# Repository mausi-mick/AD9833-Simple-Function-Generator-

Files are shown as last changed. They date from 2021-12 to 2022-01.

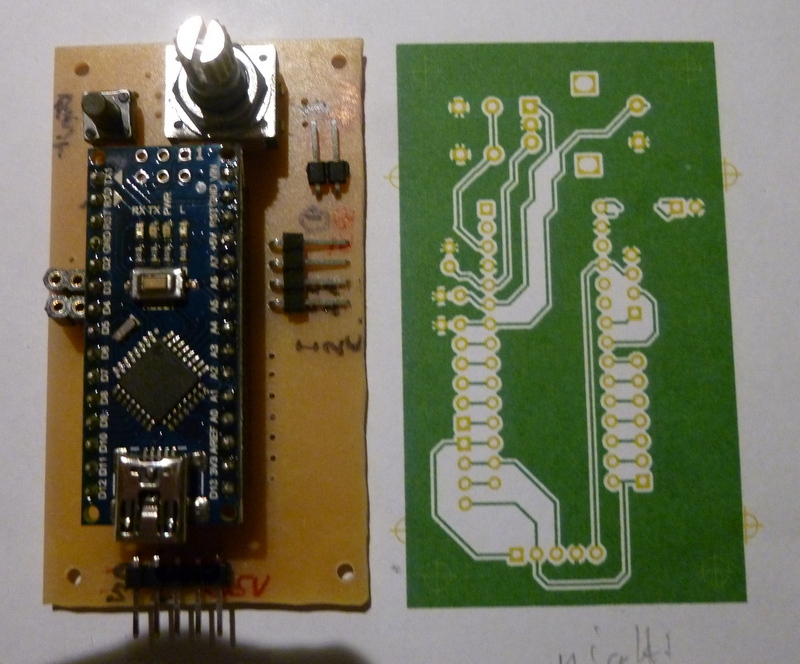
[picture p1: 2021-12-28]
P1000197.JPG

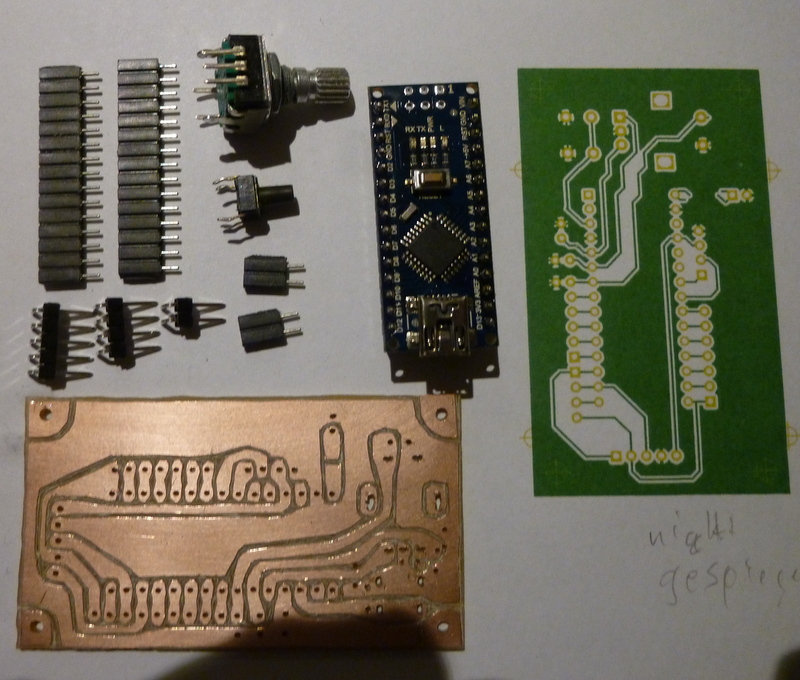
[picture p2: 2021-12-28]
P1000195.JPG

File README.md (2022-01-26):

AD9833-Simple-Function-Generator

The project based on the project "Signal Generator AD9833" from Peter Balch :
    •  https://www.instructables.com/Signal-Generator-AD9833/
    • where the input commands like Curve-Type (Sine, Triangle, Square) , Sweep or Frequency are send from a PC via USB to Arduino-Nano and from there to the AD9833 Signalgenerator-Modul.
    • I changed the program  so that it works standalone without connection to the PC.
    • For input the commands, I use only a rotary encoder with integrated push-button-switch.
    • A HD44780 display (LCD1602) shows all information (Curve-Type, Frequency, sweep ...)
    • On the encoder I use external interrupts (Pin2 / Pin3 Arduino NANO) , on push-button-switch I use Pin-Change-Interrupt (PCI) for a direct/quick response.
    • A small Video is here:   https://www.youtube.com/watch?v=DLXJh2jmxDk
    • or here: video  („TRIANGLE“) :   https://www.youtube.com/watch?v=seZB-FUj7es
    • In the new version I have expand the program with new functions inside the AD9833-Signal-Generator and outside this function with a digital ConstantCurrentSource (CCS) working from about 1µA ( starts at 10 µA ) to 4095 µA (step 1 µA) or from 10 µA to 40.95 mA (step 10 µA) .
    • I have expand now the device (and program) with a second sine-generator (AD9850) module,
    • so you have two independent siganl-sources.

So the device  includes now this functions:

    • AD9833 Signalgenerator for Sine, Triangle and Squarewave up to 12.5 Mhz in 1 Hz-Steps 
      
    • digital ConstantCurrentSource/Sink from 10 µA to 4.095 mA (Stepwidth : 1 µA) or (10 µA to 40.95 mA with stepwidth 10 µA) 
    • Low-Frequency Function-Generator for Sinus, Triangle StepUp , StepDown and Squarewave for low frequencies (mHz to some kHz) 
    • optionally : AD9850  Sine-genarator  (second siganl-source)
    • 
For small budget I use only a few parts with price over 1 $/€:

    • AD9833 board
    • AD9850 board (optional)
    • HD44780 with I2C 
    • Arduino NANO (clone?) 
    • DAC MCP4822 
    • OPV MCP6002 
    • n-Mosfet BSP89  (high Voltage, low Idss)
    • Rotary Encoder with push-button 
    • n-Mosfet for switching Rp ( from 1025 Ohm to 10.25 Ohm) with Low R-on (< 100 mOhm) 
    • 5V Zener/Ref-Diode  (or other stabilization for MCP4822/MCP6002) 
    • 2x MT3608 Step up (5V/ for NANO/LCD..., 28V for CurrentSource) 
    • Battery-holder for 18650 Battery 
    • USB  Lion-loader board 
    • 18650 Lion-Battery (one piece) 
    • 
More information in the next days.

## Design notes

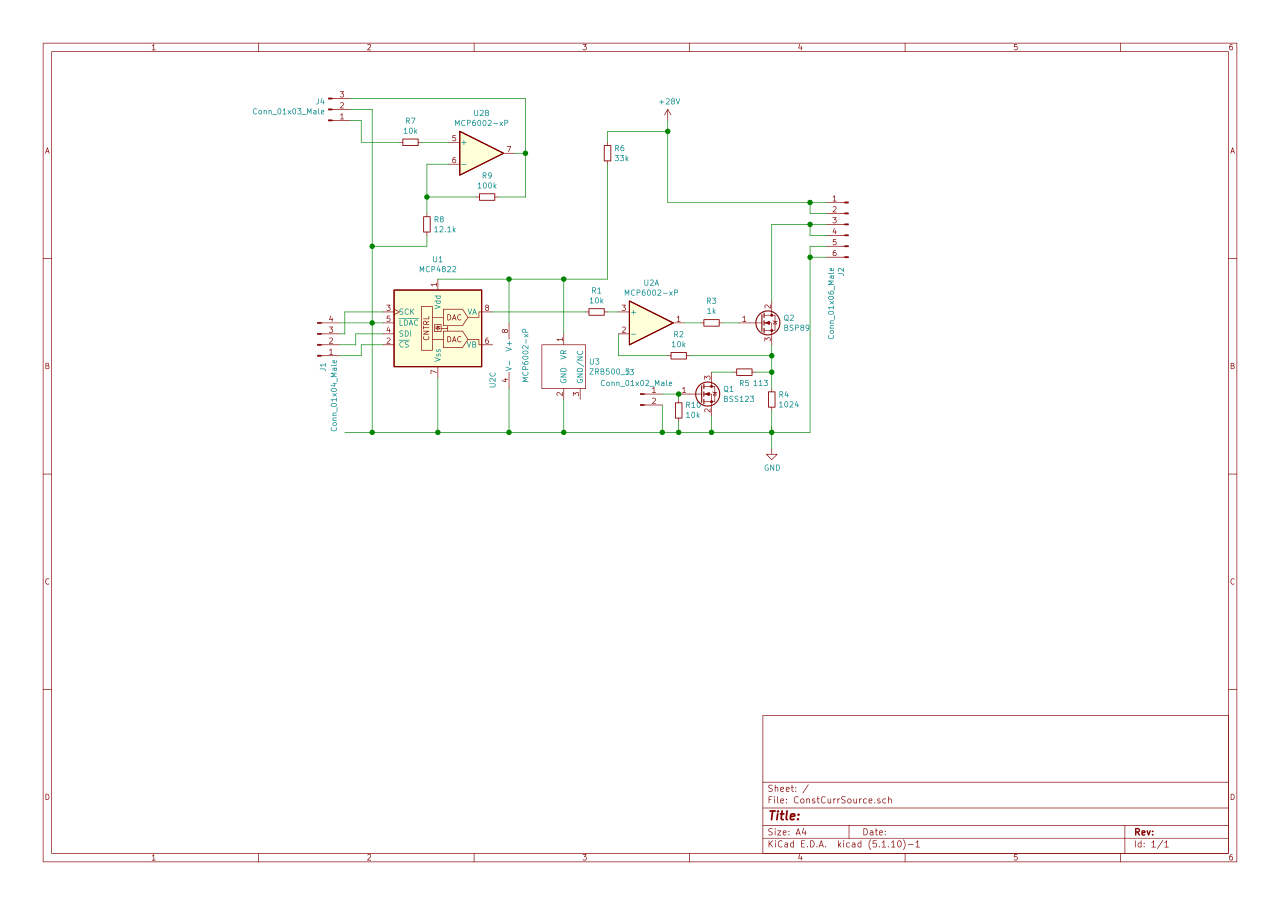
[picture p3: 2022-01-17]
ConstCurrSource(1).png

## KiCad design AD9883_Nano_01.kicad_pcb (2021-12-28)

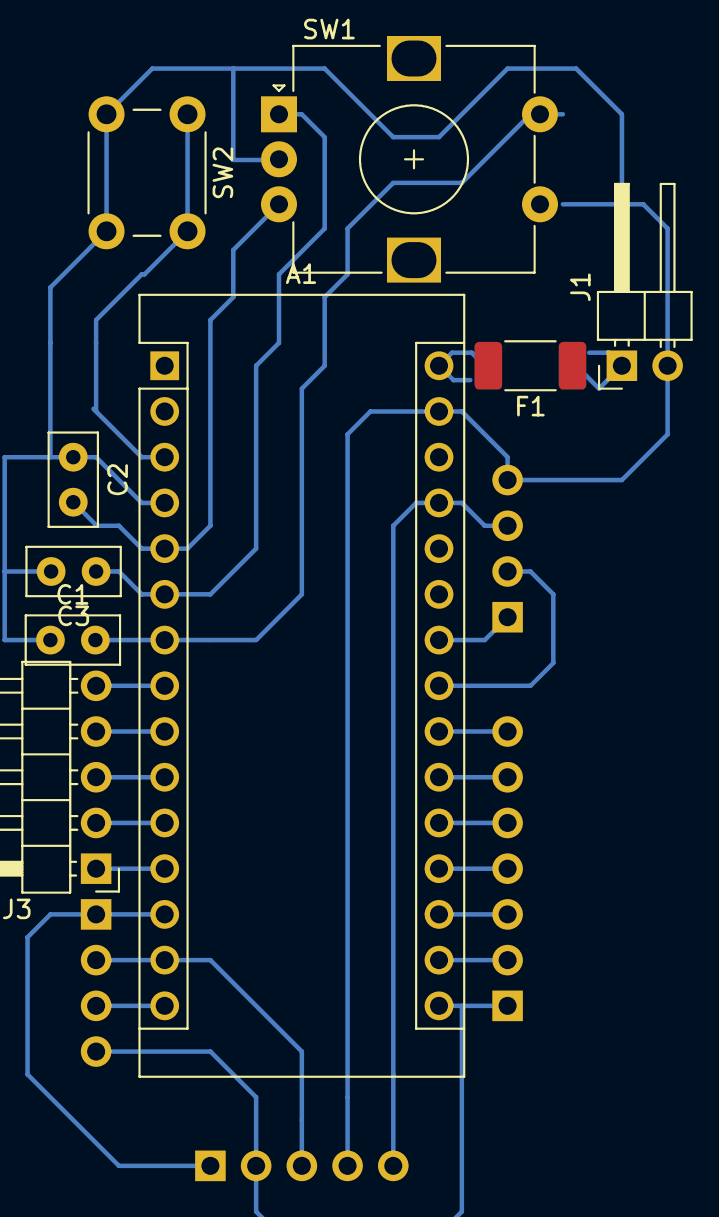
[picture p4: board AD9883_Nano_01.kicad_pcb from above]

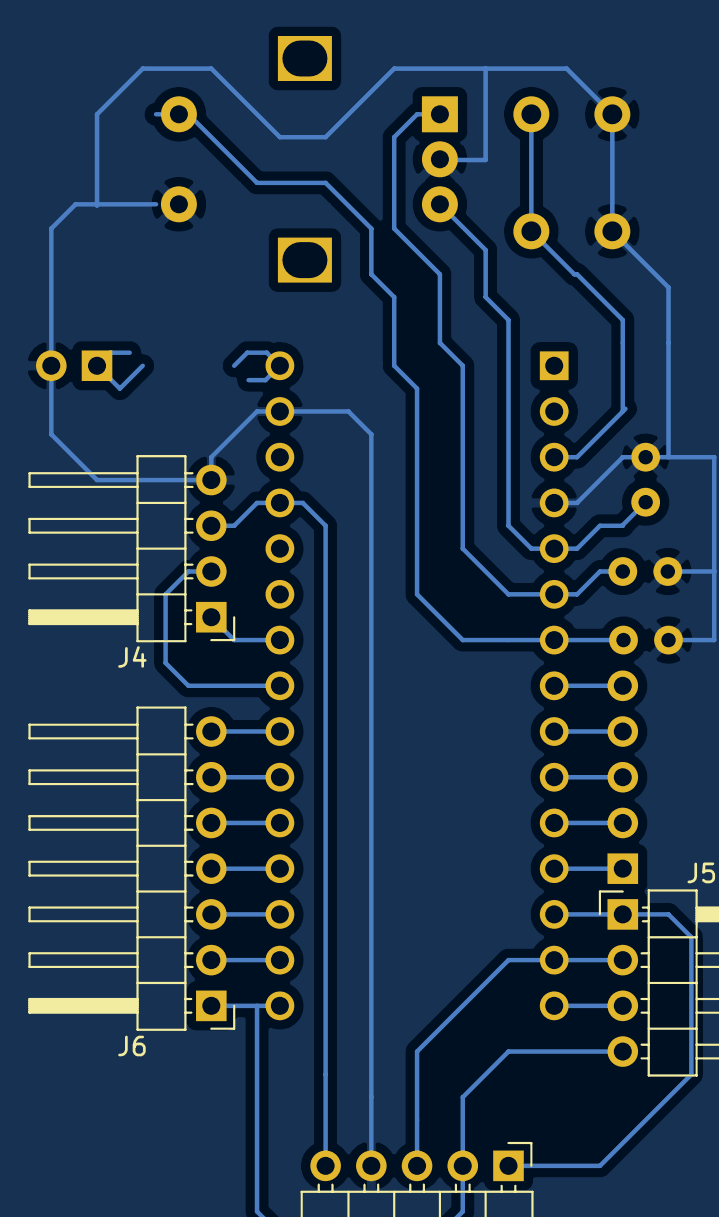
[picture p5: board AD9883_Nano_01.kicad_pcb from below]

Board: 2 copper layers, 13 parts (4 on the bottom side), 25 nets.

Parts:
A1: Arduino_Nano_v3.x; Arduino_Nano
C1, C2, C3: 10nF; C_Disc_D5.0mm_W2.5mm_P2.50mm
F1: Fuse_Small 500mA; Fuse_2010_5025Metric_Pad1.52x2.65mm_HandSolder
J1: Conn_Power_7_12V; PinHeader_1x02_P2.54mm_Horizontal
J2: Conn_to_AD9833; PinHeader_1x05_P2.54mm_Horizontal
J3: Conn_open; PinHeader_1x05_P2.54mm_Horizontal
J4: Conn_to_I2C_LCD; PinHeader_1x04_P2.54mm_Horizontal
J5: Conn_SPI; PinHeader_1x04_P2.54mm_Horizontal
J6: Conn_ADC; PinHeader_1x07_P2.54mm_Horizontal
SW1: Rotary_Encoder_Switch; RotaryEncoder_Alps_EC12E-Switch_Vertical_H20mm
SW2: SW_DIP_x01; SW_PUSH_6mm_H7.3mm

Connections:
+5V: A1.27, J2.5, J4.3
+9V: F1.1, J1.1
GND: A1.4, A1.29, C1.1, C2.1, C3.2, J1.2, J2.4, J4.4, SW1.C, SW1.S2, SW2.2
unnamed: A1.3, SW2.1
unnamed: A1.5, C2.2, SW1.B
unnamed: A1.6, C3.1, SW1.A
unnamed: A1.7, C1.2, SW1.S1
unnamed: A1.8, J3.5
unnamed: A1.9, J3.4
unnamed: A1.10, J3.3
unnamed: A1.11, J3.2
unnamed: A1.12, J3.1
unnamed: A1.13, J2.1, J5.1
unnamed: A1.14, J2.3, J5.2
unnamed: A1.15, J5.3
unnamed: A1.16, J2.2, J5.4, J6.1
unnamed: A1.17, J6.2
unnamed: A1.18, J6.3
unnamed: A1.19, J6.4
unnamed: A1.20, J6.5
unnamed: A1.21, J6.6
unnamed: A1.22, J6.7
unnamed: A1.23, J4.2
unnamed: A1.24, J4.1
unnamed: A1.30, F1.2

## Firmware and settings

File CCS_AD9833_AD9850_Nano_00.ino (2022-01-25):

//
//--------------------------------------------------------------------------------------- 
//  Thanks:
//
// Peter Balch  :  https://www.instructables.com/Signal-Generator-AD9833/               : AD9833 Source, flow-control, sweep, ...
// fhdm-devels  :  https://www.instructables.com/Simple-AD9833-Based-Signal-Generator/  : PinChangeInterrupt
// GreatScottLab:  https://www.instructables.com/DIY-FunctionWaveform-Generator/        : HD44780 display
//                 https://omerk.github.io/lcdchargen/                                  : Pixel-Generator HD44780 LCD Modules
//                 Interrupt-based (switches (PCI) by Simon Merrett, based on insight from Oleg Mazurov, Nick Gammon, rt, Steve Spence
//---------------------------------------------------------------------------------------
// subject to the GNU General Public License
//---------------------------------------------------------------------------------------
// Developped with Arduino IDE 1.8.4 / 1.8.13
//---------------------------------------------------------------------------------------
//
// CCS_AD9833_Nano_00: 2022_01_05: copy from  CCS_NanO_08 and AD9833_PCI_Nano_HD44780_02
// CCS_AD9833_Nano_01: 2022_01_08: copy from  00. Test freq-Lo with Steps like current-steps
// CCS_AD9833_Nano_02: 2022_01_22: copy from  01. Test current-source
// CCS_AD9833_Nano_03: 2022_01_25: copy from  02 and AD9850_Nano_PCI_01: Integration Sine-Gen. AD9850
// CCS_AD9833_AD9850_Nano_00: 2022_01_25: copy from CCS_AD9833_Nano_03: 
//
#include <SPI.h>                     // for DAC and AD9833
#include <AD9833.h>                  // test
#include <MCP4822.h>                 // DAC 12 bit
#include <Encoder.h>
#include <Wire.h>                    // Wire for I2C
#include <LiquidCrystal_I2C.h>       // HD55780 LCD1602

//------------------------  Encoder with ext. Interrupt: 
const int ENC_CW   =  2; // ext.Int. Pin D2 <<-- change with D3 wrong direction ???
const int ENC_CCW  =  3; // ext.int. Pin D3 <<-- change with D2 wrong direction ???
//------------------------  switches with Pin-Change-Interrupt (PCI): 

const int RESET    =  4; // AD9850 Modul
const int DATA     =  5; // AD9850 Modul
const int FQ_UD    =  6; // AD9850 Modul
const int W_CLK    =  7; // AD9850 Modul   

const int SWITCH_R =  8; // switch a resistor parallel to Rm for increasing current ##################
const int DAC_CS   =  9; // MCP4822 12-bit Dac

//------------------------  AD9833 SPI-Pins
const int SG_FSYNC = 10; // AD9833 SPI-CS
const int SG_DATA  = 11; // AD9833 SPI-MOSI
const int SG_CLK   = 13; // AD9833 SPI-SCLK

const int ENC_A0   = A0; // PCINT8  : Pin A0    // rotary encoder steps
const int ENC_A1   = A1; // PCINT9  : Pin A1    // rotary encoder steps

const int ENC_BUT  = A2; // PCINT10 : Pin A2

#define AD9850_CLOCK 125000000      // Module AD9850 crystal frequency. 


AD9833 ad9(SG_FSYNC);               // SCK and MOSI must CLK and DAT pins on the AD9833 for SPI   

LiquidCrystal_I2C lcd(0x27, 16, 2); // HEX-Address 0x27 (or 0x3F), 16 rows , 2 lines_I2C lcd(0x27, 20, 4)" 


MCP4822 dac= MCP4822(DAC_CS);       // CS-Pin 9, AD9833 on Pin 10  

Encoder myEnc(ENC_CW,ENC_CCW);

volatile int EncPos    = 0; //this variable stores our current value of encoder position. Change to int or uin16_t instead of byte if you want to record a larger range than 0-255
volatile int oldEncPos = 0; //stores the last encoder position value so we can compare to the current reading and see if it has changed (so we know when to print to the serial monitor)
volatile byte enc_dir  = 'r';
volatile uint8_t but_p = 0,but_c=0;
volatile unsigned long  incr = 0;
volatile long unsigned int freq_s = 1000,freq=1000;         // Set initial frequency.
volatile long unsigned int freqOld = freq;
volatile uint8_t s_Hz=0,s_step=0,s_upd = 1;
volatile int stepPointer = 0; 

//-----------------------------------------------------------------------------
// Global Constants
//-----------------------------------------------------------------------------
const byte numberOfDigits = 8;  // number of digits in the frequency

const uint16_t wft_s = 0x2000; // sine
const uint16_t wft_t = 0x2002; // triangle
const uint16_t wft_q = 0x2028; // square
const uint16_t wft_h = 0x2020; // halfsquare

//const int wSine     = 0b0000000000000000;
//const int wTriangle = 0b0000000000000010;
//const int wSquare   = 0b0000000000101000;
const int step_t[]    = {1,2,3,5,6,9,10,15,30};                           // step-sine  0...8          
const uint16_t sweep_t[] = {1000,2000,5000,10000,20000,50000};            // sweep-pos 
const uint16_t delay_t[] = {100,200,500,1,2,5,10,20,50,100,200,500,1000}; // delay
const long f_st[] = { 0,10,100,1000,10000,100000,1000000};                // strt frequency
const char* stepText[] = {"   1 Hz", "   2 Hz", "   5 Hz", "  10 Hz", "  20 Hz", "  50 Hz", " 100 Hz", " 200 Hz", " 500 Hz",
                            "  1 kHz", "  2 kHz", "  5 kHz", " 10 kHz", " 20 kHz", " 50 kHz", "100 kHz", "200 kHz", "500 kHz"};
String units = stepText[stepPointer];
//                     0   1   2   3   4   5   6   7   8   9  10  11  12
const char com_t[] = {'S','T','Q','L','C','H','M','P','D','G','R','X',' '};   // Menu-Commands:
// 0  'S': start Sine 
// 1  'T': start Triangle 
// 2  'Q': start Square
// 3  'L': set Freq.-Low 
// 4  'C': set Freq.-Low scroll contin. or steps 
// 5  'H': set Freq.-High
// 6  'M': swap Freq. Low  <--> High
// 7  'P': set sweep param. up/down,  step-nr
// 8  'D': set / change Delay sweep
// 9  'G': sweep 
//10  'R': Reset AD9833
//11  'X': return 

const char *str_com[]= {"Sine            ","Triangle        ","Square          ",
                        "set Low freq.   ","scroll Stepw >=1","set High freq.  ",
                        "swap Lo/Hi freq.","set sweep param.","set delay sweep ",
                        "sweep           ","Reset AD9833    ","return          "}; 

// HD44780 special-signs

const byte C_C_1_Arrow_D[8] = {  // from: https://omerk.github.io/lcdchargen/
  0b01110, 0b01010, 0b01010, 0b01010, 0b01010, 0b11011, 0b01110, 0b00100};

const byte C_C_2_Arrow_U[8] = {
  0b00100, 0b01010, 0b11011, 0b01010, 0b01010, 0b01010, 0b01010, 0b01110};

const byte C_C_3_Arrow_L[8] = {
  0b00010, 0b00100, 0b01111, 0b11000, 0b01111, 0b00100, 0b00010, 0b00000};

const byte C_C_4_Arrow_R[8] = { 
  0b01000, 0b00100, 0b11110, 0b00001, 0b11110, 0b00100, 0b01000, 0b00000};
  
const byte C_C_5_Tilde[8]  = { 
  0b00000, 0b00000, 0b00000, 0b01000, 0b10101, 0b00010, 0b00000, 0b00000};
/*
const byte C_C_5_Line_D[8] = {
  0b00000, 0b00000, 0b11111, 0b00000, 0b11111, 0b00000, 0b00000, 0b00000};

const byte C_C_6_Sine_1[8] = { //  Sinus oben
  0b01110, 0b11011, 0b10001, 0b00000, 0b00000, 0b00000, 0b00000, 0b00000};


const byte C_C_7_Sine_2[8] = {// Sinus oben links nach unten
  0b00000, 0b00000, 0b10000, 0b11000, 0b01110, 0b00011, 0b00001, 0b00000};


const byte C_C_8_Sine_3[8] = {// Sinus unten
  0b00000, 0b00000, 0b00000, 0b00000, 0b00000, 0b10001, 0b11011, 0b01110};


const byte C_C_9_Sine_4[8] = {// Sinus von unten links nach oben rechts
  0b00000, 0b00000, 0b00011, 0b01111, 0b01100, 0b11000, 0b10000, 0b00000};

*/

//-----------------------------------------------------------------------------
// Global Variables
//-----------------------------------------------------------------------------

uint8_t  freqSave[numberOfDigits] = {0,0,1,0,0,0,0,0}; //   100 Hz 
uint8_t  freqSGLo[numberOfDigits] = {0,0,1,0,0,0,0,0}; //   100 Hz 
uint8_t  freqSGHi[numberOfDigits] = {0,0,0,0,2,0,0,0}; // 20000 Hz 

uint8_t  func_t[] = {0,1,2,3,4};
uint8_t  digi_t[] = {0,0,0,0};

uint32_t time_t[] = {0,1,2,5,10,20,50,100,200,500};    // µs 0...9
uint32_t time_m[] = {1,2,5,10,20,50,100,200,500,800};  // ms 0...9 // 10 ... 19
uint32_t time_s[] = {1,2,5,10,20,30,50,60,100,120};    // s  0...9 // 20 ... 29

int32_t  fact_t[] = {1,2,5,10,20,50,100,200,500,1000};
long     dig4_0_t[] = {0,0,0,0,0};

long     ilm=0,ilt=0,ifu=9,istep=0,zconst,fox=100,fstart=0,f_lowo=100,gainy=10,oldPos=-999,newPos=0;
int8_t   pos_i=15,pos_o=15,dig_o=0,dig_n=0,s_sel,ila=2,ido=10,ioo=0,igo=10,line_d=0,sel_c=0,hz_nr=0,sweep_r=0;;
int16_t  iso=10,ist=0,zwave_t = wft_s;        // sine
int32_t  time_del=10,delay_s=0,off_s=0,off_r=0;
unsigned long time_f,time_l,time_d,time_n;
long     fact=1,fact_o=1,iconst=0,fac_i=0,offs=0;
uint8_t  s_first=0,digi,s_ms=0,s_del=0,s_stepa=0,s_par=0,s_end=0,s_kHz=0,s_sweep=0;
uint8_t  s_low=0,sel_o=0,dmax=0,freq_zw=0,tab_nr=0,s_sine=0;
//int  waveType = wSine;

char c = ' ',com_o = 'S'; // old command

int i_del=3,i_sw=2,grad,step_s=1,stap=0,endp=1,iao,ieo;    // 4 ?
uint8_t posc_t[] = {7, 5};
int delay_micros = 1000;  // 1ms
int sweep_nr     = 5000;  

int SG_iSweep,SG_nSweep;

int16_t sinx = 0,ils; 

float wert=0.0,gainf=1.0;


#define pulseHigh(pin) {digitalWrite(pin, HIGH); digitalWrite(pin, LOW); }


 // transfers a byte, a bit at a time, LSB first to the 9850 via serial DATA line
void tfr_byte(byte data) {
  for (int i = 0; i < 8; i++, data >>= 1) {
    digitalWrite(DATA, data & 0x01);
    pulseHigh(W_CLK);   //after each bit sent, CLK is pulsed high
  }
}

void sendFrequency(double frequency) {
  int32_t freq1 = frequency * 4294967295/AD9850_CLOCK;  // note 125 MHz clock on 9850
  for (int b = 0; b < 4; b++, freq1 >>= 8) {
    tfr_byte(freq1 & 0xFF);
  }
  tfr_byte(0x000);                     // Final control byte, all 0 for 9850 chip
  pulseHigh(FQ_UD);                    // Done!  Should see output
}



//-----------------------------------------------------------------------------
// Main routines
// The setup function
//-----------------------------------------------------------------------------
void setup() {

// Serial.begin(115200);  //  Open serial port

  pinMode(ENC_CW,  INPUT_PULLUP);
  pinMode(ENC_CCW, INPUT_PULLUP);

  pinMode(ENC_A0,  INPUT_PULLUP);     // A0 PCINT8
  pinMode(ENC_A1,  INPUT_PULLUP);     // A1 PCINT9
  pinMode(ENC_BUT, INPUT_PULLUP);     // A2 PCINT10  
 
  cli();
 // Configure interrupt and enable for rotary encoder.
 // PCICR |= (1 << PCIE2);                      // Port: D
 // PCMSK2 |= (1 << PCINT18) | (1 << PCINT19);  // D2, D3
  PCICR =  0b00000010;   // Port: C / PCIE1: Pin Change Interrupt Enable 1
  PCMSK1 = 0b00000111;   // Enable Pin Change Interrupt for A0,A1,A2 // - A3
  sei();
 /*  
   PCICR  = 0b00000100;   // PCIE2: Pin Change Interrupt Enable 2 // Port D (D0...D7)
 //PMMSK2 = 0b00011100;    // Enable Pin Change Interrupt for D2 - D4
 //PMMSK2 = 0b00001100;    // Enable Pin Change Interrupt for D2 - D3
  PCMSK2 = 0b00010000;   // Enable Pin Change Interrupt for D4
*/
  pinMode(FQ_UD, OUTPUT);              // Configure pins for output to AD9850 module.
  pinMode(W_CLK, OUTPUT);
  pinMode(DATA, OUTPUT);
  pinMode(RESET, OUTPUT);
  
  pinMode(SWITCH_R, OUTPUT);
  digitalWrite(SWITCH_R, LOW);  // sets the digital pin off

  pinMode(DAC_CS, OUTPUT);
  digitalWrite(DAC_CS, HIGH);  // sets the digital pin HIGH inactiv

  lcd.begin();                  //  HD44780

  // HD44780 special signs
  lcd.createChar(1, C_C_1_Arrow_D);  //########### Down
  lcd.createChar(2, C_C_2_Arrow_U);  //########### Up
  lcd.createChar(3, C_C_3_Arrow_L);  //########### Left
  lcd.createChar(4, C_C_4_Arrow_R);  //########### Right
  lcd.createChar(5, C_C_5_Tilde);    //########### Tilde 
  //lcd.createChar(5, C_C_5_Line_D);   //########### Line
  //lcd.createChar(6, C_C_6_Sine_1);   //########### Sine Top
  //lcd.createChar(7, C_C_7_Sine_2);   //########### Sine Down
  //lcd.createChar(1, C_C_8_Sine_3);   //########### Sine Bottom
  //lcd.createChar(2, C_C_9_Sine_4);   //########### Sine Up
  
  lcd.backlight(); //switch-on backlight,  lcd.noBacklight(); switch-off backlight 
  int8_t ilx=0,ily=1,ilz;
  for (uint8_t ill = 0;ill<5;ill++) {
    lcd.setCursor(0,ilx); lcd.print("Const.Cur.Source");  
    lcd.setCursor(0,ily); lcd.print("AD9833 Func.Gen.");
    ilz = ily;
    ily = ilx;
    ilx = ilz;
    delay(500);
  }  

// SPI.beginTransaction (SPISettings (8000000, MSBFIRST, SPI_MODE0));  // for AD9833 max 12.5 MHz, MCP4822: 20 MHz
// SPI.begin();

  delay(200);

  sel_c = 11;// "Sine " at start-display
  oldEncPos = 999;
  fillBlank(0,0,16); 
  fillBlank(0,1,16); 
}

void startDAC() {
 
  SPI.beginTransaction (SPISettings (20000000, MSBFIRST, SPI_MODE0));  // for AD9833 max 12.5 MHz, MCP4822: 20 MHz
  SPI.begin();
  
  dac.begin();
   // Configure analog outputs
  dac.off_B();
  dac.setGain2X_A();  // _AB();

  delay(200);
  
}



ISR (PCINT1_vect) {  // Port C  A0...A5 ??
  
  // If interrupt is triggered by the button
  if (!digitalRead(ENC_BUT)) but_p = 1;    // Pin A2: Push-Button pressed

}

/*
ISR (PCINT2_vect) {
  
  // If interrupt is triggered by the button
  if (!digitalRead(ENC_BUT)) but_p = 1;;    // Pin4: Push-Button pressed

}
*/
void fillBlank(uint8_t col, uint8_t line, uint8_t nr) {
  if (nr == 0) return;
  lcd.setCursor(col,line);
  for (uint8_t l=0;l<nr;l++)  {
    lcd.print(" ");
  }
}

//-----------------------------------------------------------------------------
//returns 10^y
//-----------------------------------------------------------------------------
unsigned long Power(int y) {
  unsigned long t = 1;
  for (byte i = 0; i < y; i++)
    t = t * 10;
  return t;
}

//-----------------------------------------------------------------------------
//calculate the frequency from the array.
//-----------------------------------------------------------------------------
unsigned long calcFreq(byte* freqSG) {
  unsigned long i = 0;
  for (byte x = 0; x < numberOfDigits; x++)
    i = i + freqSG[x] * Power(x);
  return i;
}

//-----------------------------------------------------------------------------
// calculate freq-array from the frequency (8-digits)
//-----------------------------------------------------------------------------
void printFreq(long freq) {
  long fo=freq,pot;
  int8_t zw=0,tab_l=numberOfDigits-1;// 8 tab-length - 1: 7... 0
  
  dmax = 0;
 
  for (int8_t ilc=tab_l;ilc>=0;ilc--) {  //4...0
 //   freqSGLo[ilc] = 0;
    pot = 1;
    if (ilc > 0) pot = Power(ilc);
    zw = fo/pot;
    if (zw > 0)  {
      if (dmax == 0) dmax = ilc;
      fo = fo - zw*pot;  
 //   freqSGLo[ilc] = zw;
      lcd.print(zw); 
    }  
    else {
      if (dmax == 0)  lcd.print(" ");
      else            lcd.print(zw); 
    }
  }

}



//-----------------------------------------------------------------------------
// calculate iconst-array from the iconst (5-digits)
//-----------------------------------------------------------------------------
void printIconst(long ic) {
  long fo=ic,pot;
  int8_t zw=0,tab_l=5-1;   // 5=tab-length - 1: 4 ... 0
  
  dmax = 0;
 
  for (int8_t ilc=tab_l;ilc>=0;ilc--) {  //4...0
    dig4_0_t[ilc] = 0;
    pot = 1;
    if (ilc > 0) pot = Power(ilc);
    zw = fo/pot;
    if (zw > 0)  {
      if (dmax == 0) dmax = ilc;
      fo = fo - zw*pot;  
      dig4_0_t[ilc] = zw;
      lcd.print(zw); 
    }  
    else {
      if (dmax == 0)  lcd.print(" ");
      else            lcd.print(zw); 
    }
  }

}


//-----------------------------------------------------------------------------
// calculate iconst-array from the iconst (5-digits)
//-----------------------------------------------------------------------------
void printIstep(long ist) {
  if      (ist >= 1000)  
    lcd.print(ist);
  else if (ist >=  100)  {
    lcd.print(" ");
    lcd.print(ist);
  }
  else if (ist >=  10)   {
    lcd.print("  ");
    lcd.print(ist);
  }
  else                   {
    lcd.print("   ");
    lcd.print(ist);
  }
}

/*
//-----------------------------------------------------------------------------
// SG_WriteRegister
//-----------------------------------------------------------------------------
void SG_WriteRegister(word dat) {
  digitalWrite(SG_CLK, LOW);
  digitalWrite(SG_CLK, HIGH);

  digitalWrite(SG_FSYNC, LOW);
  for (byte i = 0; i < 16; i++) {
    if (dat & 0x8000)
      digitalWrite(SG_DATA, HIGH);
    else
      digitalWrite(SG_DATA, LOW);
    dat = dat << 1;
    digitalWrite(SG_CLK, HIGH);
    digitalWrite(SG_CLK, LOW);
  }
  digitalWrite(SG_CLK, LOW);   //#HIGH
  digitalWrite(SG_FSYNC, HIGH);
  digitalWrite(SG_FSYNC, HIGH);
}

//-----------------------------------------------------------------------------
// SG_Reset
//-----------------------------------------------------------------------------
void SG_Reset() {
  delay(100);
  SG_WriteRegister(0x100);
  delay(100);
}

//-----------------------------------------------------------------------------
// SG_freqReset
//    reset the SG regs then set the frequency and wave type
//-----------------------------------------------------------------------------
void SG_freqReset(long frequency, int wave) {
  long fl = frequency * (0x10000000 / 25000000.0);
  SG_WriteRegister(0x2100);
  SG_WriteRegister((int)(fl & 0x3FFF) | 0x4000);
  SG_WriteRegister((int)((fl & 0xFFFC000) >> 14) | 0x4000);
  SG_WriteRegister(0xC000);
  SG_WriteRegister(wave);
  waveType = wave;
}

//-----------------------------------------------------------------------------
// SG_freqSet
//    set the SG frequency regs 
//-----------------------------------------------------------------------------
void SG_freqSet(long frequency, int wave) {
  long fl = frequency * (0x10000000 / 25000000.0);
  SG_WriteRegister(0x2000 | wave);
  SG_WriteRegister((int)(fl & 0x3FFF) | 0x4000);
  SG_WriteRegister((int)((fl & 0xFFFC000) >> 14) | 0x4000);
}
*/


//-----------------------------------------------------------------------------
// SG_StepSweep
//    increment the FG frequency 
//-----------------------------------------------------------------------------
void SG_StepSweep(void) {
  if (SG_iSweep > SG_nSweep) SG_iSweep = 0;
  long f = exp((log(calcFreq(freqSGHi)) - log(calcFreq(freqSGLo)))*SG_iSweep/SG_nSweep + log(calcFreq(freqSGLo))) +0.5;
  if (s_sine == 0) { 
    ad9.ApplySignal(zwave_t,REG0,f); // 
    ad9.EnableOutput(true);   // Turn ON the output - it defaults to OFF
  }
  else sendFrequency(f); // AD9850
  
 // SG_freqSet(f, waveType);
  SG_iSweep++;
}
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
void loop(){
    int8_t s_first = 0; 
    s_low   = 0;
    but_p   = 0;
    sel_c   = 0;    // ??
    EncPos    = 999;
    oldEncPos = 999;
    lcd.setCursor(0,0); lcd.print("Select Function:");
    while (but_p == 0)  {        // button-switch not pressed
      EncPos = myEnc.read();     //###################################
      if (oldEncPos != EncPos) {  
        if (s_first == 0) s_first = 1;
        else {
          s_first = 0;
          if (EncPos > oldEncPos) ila++;
          else                    ila--;
          if (ila > 3) ila = 0;   
          if (ila < 0) ila = 3;
          lcd.setCursor(0,1); //lcd.print(ila);
          if      (ila == 0) lcd.print("AD9833-Func-Gen.");
          else if (ila == 1) lcd.print("Const.Cur.Source");
          else if (ila == 2) lcd.print("LowFreq-Func-Gen");
          else if (ila == 3) lcd.print("AD9850-Sine-Gen.");
          delay(100);
       } // if
       oldEncPos = EncPos;
     } // if  
   } // while     
   but_p = 0;  
   if      (ila == 0) {  // AD9833-Func-Gen.
     fillBlank(0,1,16);
     lcd.setCursor(0,0);lcd.print("AD9833-Func-Gen."); 
     delay(100);

     SPI.beginTransaction (SPISettings (12500000, MSBFIRST, SPI_MODE0));  // for AD9833 max 12.5 MHz, MCP4822: 20 MHz
     SPI.begin();
     
     delay(200);  
     ad9.Begin();
     ad9.ApplySignal(SINE_WAVE,REG0,1111);
     ad9.EnableOutput(true);   // Turn ON the output - it defaults to OFF
    
     controlAD9833();  //########################################
     digitalWrite(SG_FSYNC,HIGH);    // disable AD9833  ?? dual-generator
   }
   else if (ila == 1) {  // Const.Cur.Source
     fillBlank(0,1,16);
     lcd.setCursor(0,0);lcd.print("Const.Cur.Source"); 
     delay(1000);
     startDAC();
     istep = 0;
     set_Iconst();
     dac.off_A();
     digitalWrite(DAC_CS,HIGH);  
   }  
   else if (ila == 2) {  // Const.Cur.Graph
     fillBlank(0,1,16);
     lcd.setCursor(0,0);lcd.print("LowFreq-Func-Gen"); 
     delay(1000);
     startDAC(); 
     ConstCurGraph();
     dac.off_A();
     digitalWrite(DAC_CS,HIGH);
   }
   else if (ila == 3) {  // AD9850-Sine-Gen.
     s_sine = 1;
     fillBlank(0,1,16);
     lcd.setCursor(0,0);lcd.print("AD9850-Sine-Gen."); 
     delay(100);
      // Initialise the AD9850 module. 
     pulseHigh(RESET);
     pulseHigh(W_CLK);
     pulseHigh(FQ_UD);    // this pulse enables serial mode - Datasheet page 12 figure 10  
       
     controlAD9833();     // modified for AD9850  ########
  
   }
   but_p = 0;  
   delay(100);
}

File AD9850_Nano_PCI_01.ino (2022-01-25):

//
//--------------------------------------------------------------------------------------- 
//  Thanks:
//
// http://www.vwlowen.co.uk/arduino/AD9850-waveform-generator/AD9850-waveform-generator.htm
//
//---------------------------------------------------------------------------------------
// subject to the GNU General Public License
//---------------------------------------------------------------------------------------
// Developped with Arduino IDE 1.8.4 / 1.8.13
//---------------------------------------------------------------------------------------
//
/* Based on AD9851 code from Andrew Smallbone - modified for AD9850
   http://www.rocketnumbernine.com/2011/10/25/programming-the-ad9851-dds-synthesizer 
 */

#include <Adafruit_GFX.h>       // Core graphics library https://github.com/adafruit/Adafruit-GFX-Library
//#include <Adafruit_ST7735.h>   // Hardware-specific library https://github.com/adafruit/Adafruit-ILI9341-Library
#include <Adafruit_ILI9341.h>    // Hardware-specific library https://github.com/adafruit/Adafruit-ILI9341-Library
#include <SPI.h>

//#include <Rotary.h>            //  Rotary encoder: https://github.com/brianlow/Rotary 
#include <Encoder.h>
Encoder myEnc(2,3);
//int TFT_LED = 9;
#define TFT_SCLK 13             // 1.8" TFT Display.
#define TFT_MOSI 11             //
#define TFT_CS   10
#define TFT_RST  -1  
#define TFT_DC    9

Adafruit_ILI9341 tft = Adafruit_ILI9341(TFT_CS,  TFT_DC, TFT_RST);

#define AD9850_CLOCK 125000000         // Module crystal frequency. Tweak here for accuracy.

#define W_CLK 7 //4                        // 8 AD9850 Module pins.    
#define FQ_UD 6 //7       
#define DATA  5 //6       
#define RESET 4 //5     

#define ENC_A0  A0                    // Set 'Step' rotary encoder pins
#define ENC_A1  A1
// PCINT10 : Pin A2
int ENC_BUT  = A2;                     // 'Step' rotary encoder's push button - Set 1 Hz steps.
// PCINT11 : Pin A3
//int force_kHz = A3;                     // Interrupt-driven encoder's push button - force 1kHz freq.
/*
Rotary i = Rotary(ENC_A0, ENC_A1); // Rotart encoder for setting increment.
Rotary r = Rotary(2, 3);               // Rotary encoder for frequency connects to interrupt pins
*/
volatile long unsigned int freq_s = 1000,freq=1000;         // Set initial frequency.
volatile long unsigned int freqOld = freq;

long oldPos = -999,newPos=0;
long int timer;

const char* stepText[] = {"   1 Hz", "   2 Hz", "   5 Hz", "  10 Hz", "  20 Hz", "  50 Hz", " 100 Hz", " 200 Hz", " 500 Hz",
                            "  1 kHz", "  2 kHz", "  5 kHz", " 10 kHz", " 20 kHz", " 50 kHz", "100 kHz", "200 kHz", "500 kHz"};
const long f_st[] = { 0,10,100,1000,10000,100000,1000000};
volatile uint8_t s_Hz=0,s_dirty = 0,s_step=0,s_upd = 0;
volatile int8_t ist = 0;
volatile int stepPointer = 0; 
volatile unsigned long  incr = 0;
String units = stepText[stepPointer];

#define pulseHigh(pin) {digitalWrite(pin, HIGH); digitalWrite(pin, LOW); }


 // transfers a byte, a bit at a time, LSB first to the 9850 via serial DATA line
void tfr_byte(byte data) {
  for (int i = 0; i < 8; i++, data >>= 1) {
    digitalWrite(DATA, data & 0x01);
    pulseHigh(W_CLK);   //after each bit sent, CLK is pulsed high
  }
}

void sendFrequency(double frequency) {
  int32_t freq1 = frequency * 4294967295/AD9850_CLOCK;  // note 125 MHz clock on 9850
  for (int b = 0; b < 4; b++, freq1 >>= 8) {
    tfr_byte(freq1 & 0xFF);
  }
  tfr_byte(0x000);                     // Final control byte, all 0 for 9850 chip
  pulseHigh(FQ_UD);                    // Done!  Should see output
}


void setup() {
  
  pinMode(2, INPUT_PULLUP);            // Pins for interrupt-driven rotary encoder and push buttons
  pinMode(3, INPUT_PULLUP);

  pinMode(ENC_A0,    INPUT_PULLUP);     // A0 PCINT8  Pins for step rotary encoder on analogue pins A2, A3
  pinMode(ENC_A1,    INPUT_PULLUP);     // A1 PCINT9
  pinMode(ENC_BUT,  INPUT_PULLUP);     // A2 PCINT10    
 // pinMode(force_kHz, INPUT_PULLUP);     // A3 PCINT11
  
  pinMode(FQ_UD, OUTPUT);              // Configure pins for output to AD9850 module.
  pinMode(W_CLK, OUTPUT);
  pinMode(DATA, OUTPUT);
  pinMode(RESET, OUTPUT);
  
 //pinMode(TFT_RST, OUTPUT);            // Configure pins for output to TFT display.
  pinMode(TFT_DC, OUTPUT);
  //pinMode(TFT_LED, OUTPUT);
 
  //analogWrite(TFT_LED, 255);           // Adjust backlight brightness.
 cli();
 // Configure interrupt and enable for rotary encoder.
 // PCICR |= (1 << PCIE2);                      // Port: D
 // PCMSK2 |= (1 << PCINT18) | (1 << PCINT19);  // D2, D3
  PCICR =  0b00000010;   // PCIE2: Pin Change Interrupt Enable 1
  PCMSK1 = 0b00000111;   // Enable Pin Change Interrupt for A0,A1,A2 // - A3
  sei();
  

 // tft.initR(INITR_BLACKTAB);           // initialize a ILI9341S chip, black tab
  tft.begin();
  tft.setRotation(3); 
  tft.setTextWrap(false);              // Allow text to run off right edge
  tft.fillScreen(ILI9341_BLACK);
   
  tft.setCursor(15, tft.height() -20);
  tft.setTextSize(1);
  tft.drawFastHLine(0, tft.height() - 23, tft.width()-10, ILI9341_BLUE);
  tft.setTextColor(ILI9341_BLUE);
  tft.println("AD9850 1 Hz to 5 MHz ");
  tft.print("   sinewave generator");
  
  // Initialise the AD9850 module. 
  pulseHigh(RESET);
  pulseHigh(W_CLK);
  pulseHigh(FQ_UD);    // this pulse enables serial mode - Datasheet page 12 figure 10  
  
  updateDisplay();       // Update the TFT display.
}

void getStep() {
  switch(stepPointer) {
    case  0:  incr =      1; break;
    case  1:  incr =      2; break;
    case  2:  incr =      5; break;
    case  3:  incr =     10; break;
    case  4:  incr =     20; break;
    case  5:  incr =     50; break;
    case  6:  incr =    100; break;
    case  7:  incr =    500; break;
    case  9:  incr =   1000; break;
    case 10:  incr =   2000; break;
    case 11:  incr =   5000; break;
    case 12:  incr =  10000; break;
    case 13:  incr =  20000; break;
    case 14:  incr =  50000; break;
    case 15:  incr = 100000; break;
    case 16:  incr = 200000; break;
    case 17:  incr = 500000; break;
  } 
}
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
